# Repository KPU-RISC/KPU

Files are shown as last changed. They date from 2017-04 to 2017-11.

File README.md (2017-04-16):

# KPU - the RISC based Open Source CPU
This repository contains complete source code and buillding files for the KPU - a RISC based CPU (Central Processing Unit). The whole CPU is emulated, simulated, and modelled on the lowest level only with primitive AND, OR, XOR, and NOT gates.

It implements a 8-bit wide Data Bus, and a 16-bit wide Address Bus. The following 8-bit wide registers are implemented:
<ul>
<li><b>D</b> (General Purpose)</li>
<li><b>E</b> (General Purpose)</li>
<li><b>F</b> (General Purpose)</li>
<li><b>G</b> (General Purpose)</li>
<li><b>H</b> (General Purpose)</li>
<li><b>XL</b> (Lower part of the 16-bit wide "X" register</li>
<li><b>XH</b> (Upper part of the 16-bit wide "X" register</li>
</ul>

The following 16-bit wide registers are implemented:
<ul>
<li><b>SP</b> (Stack Pointer)</li>
<li><b>BP</b> (Base Pointer)</li>
<li><b>PC</b> (Program Counter)</li>
<li><b>M</b> (Memory Addressing)</li>
<li><b>J</b> (Jump Destination Addressing)</li>
<li><b>X</b> (General Purpose)</li>
<li><b>Y</b> (General Purpose)</li>
<li><b>Z</b> (General Purpose)</li>
</ul>

The project contains the following sub components:
<ul>
<li><b>Assembler</b>: The Assembler generates from the assembly language binary code that can be executed by the CPU. It is written in C#, and uses ANTLR for the syntax processing.</li>
<li><b>Emulation</b>: The C#-based Emulator is able to run binary code in a Console application or within a WinForms application (used for debugging purposes).</li>
<li><b>VHDL</b>: This folder contains the whole CPU implementation as VHDL description files.</li>
<li><b>Eagle</b>: This folder contains the whole schematics and board files ready for a physical implementation of the CPU based on 74LS TTL logic chips.</li>
<li><b>Logicly</b>: This folder contains early Proof-Of-Concept files for the Logicly simulation program.</li>
</ul>

For more detailed technical information about the CPU, please visit the project website at http://www.cpu-design.at

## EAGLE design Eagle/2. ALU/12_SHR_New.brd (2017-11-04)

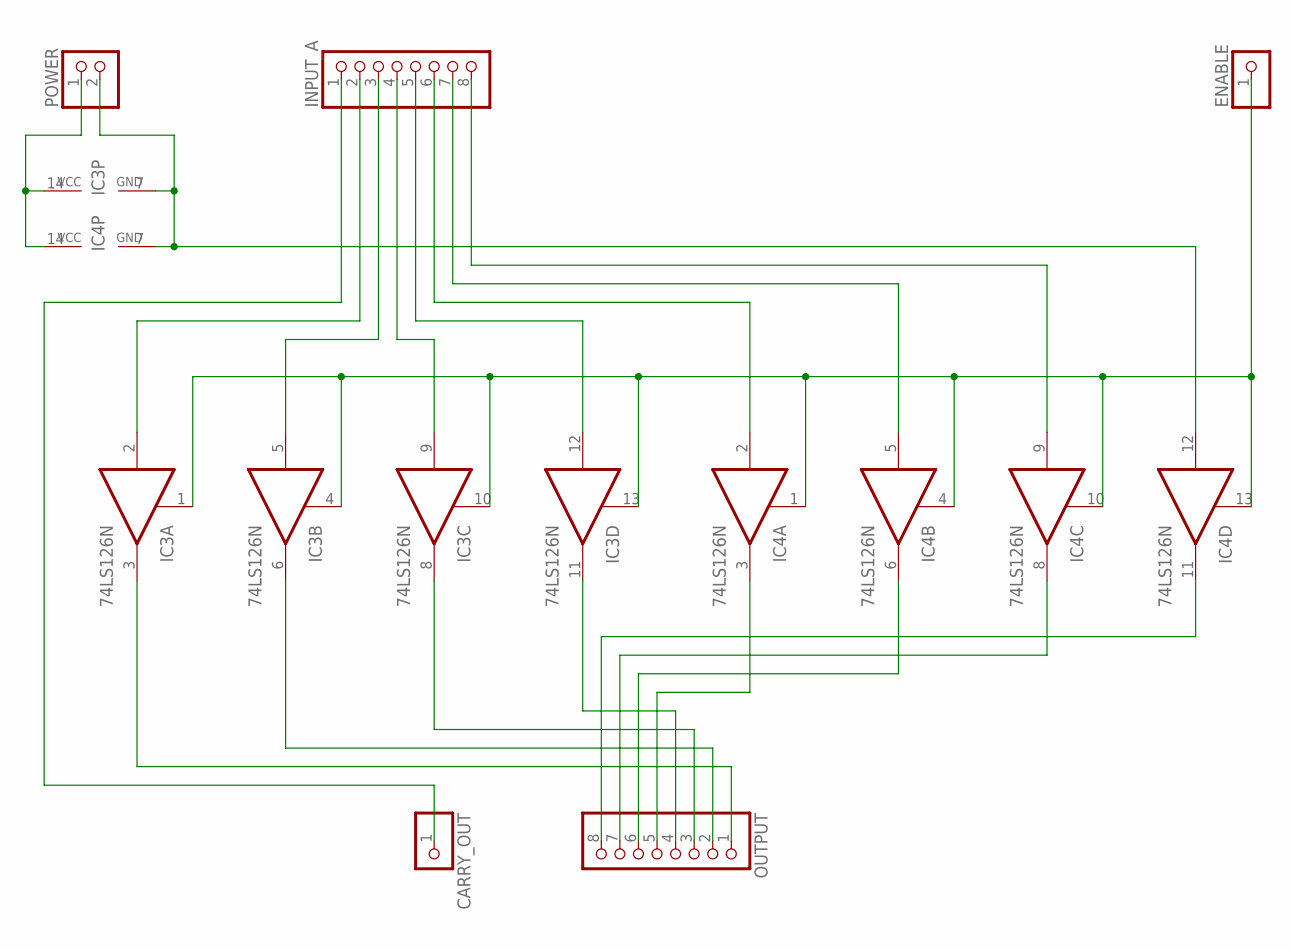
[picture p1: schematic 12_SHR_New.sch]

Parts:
CARRY_OUT: PINHD-1X1; 1X01
ENABLE: PINHD-1X1; 1X01
IC3, IC4: 74LS126N; DIL14
INPUT_A: PINHD-1X8; 1X08
OUTPUT: PINHD-1X8; 1X08
POWER: PINHD-1X2; 1X02

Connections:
GND: IC3.7 (GND), IC4.7 (GND), IC4.12 (I), POWER.2
unnamed: CARRY_OUT.1, INPUT_A.1
unnamed: IC3.2 (I), INPUT_A.2
unnamed: IC3.12 (I), INPUT_A.5
unnamed: IC4.2 (I), INPUT_A.6
unnamed: IC4.5 (I), INPUT_A.7
unnamed: IC4.9 (I), INPUT_A.8
unnamed: IC3.5 (I), INPUT_A.3
unnamed: IC3.9 (I), INPUT_A.4
unnamed: IC3.3 (O), OUTPUT.1
unnamed: IC3.6 (O), OUTPUT.2
unnamed: IC3.8 (O), OUTPUT.3
unnamed: IC3.11 (O), OUTPUT.4
unnamed: IC4.3 (O), OUTPUT.5
unnamed: IC4.6 (O), OUTPUT.6
unnamed: IC4.8 (O), OUTPUT.7
unnamed: IC4.11 (O), OUTPUT.8
unnamed: ENABLE.1, IC3.1 (OE), IC3.4 (OE), IC3.10 (OE), IC3.13 (OE), IC4.1 (OE), IC4.4 (OE), IC4.10 (OE), IC4.13 (OE)
VCC: IC3.14 (VCC), IC4.14 (VCC), POWER.1

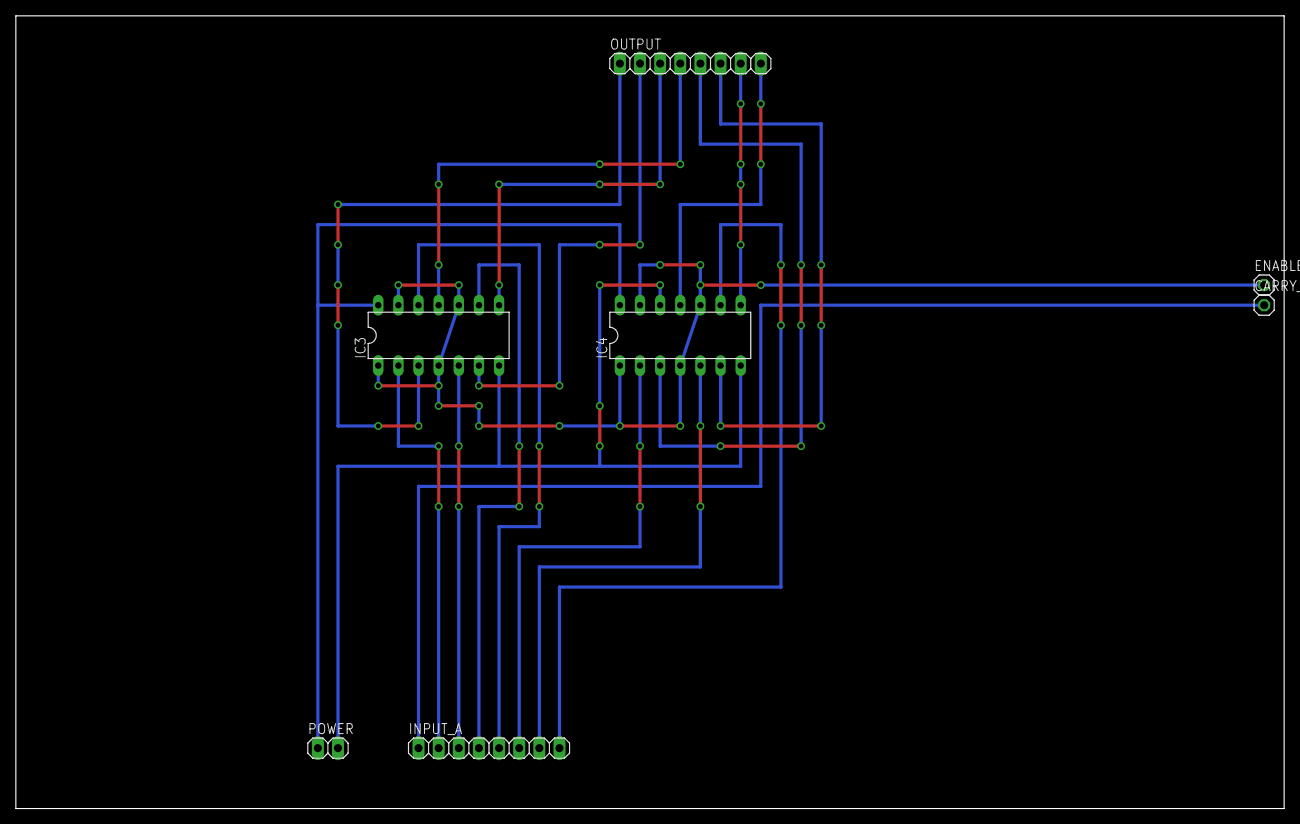
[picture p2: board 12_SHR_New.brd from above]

Board: 2 copper layers, 160.0 x 100.0 mm, 7 parts (0 on the bottom side), 19 nets.

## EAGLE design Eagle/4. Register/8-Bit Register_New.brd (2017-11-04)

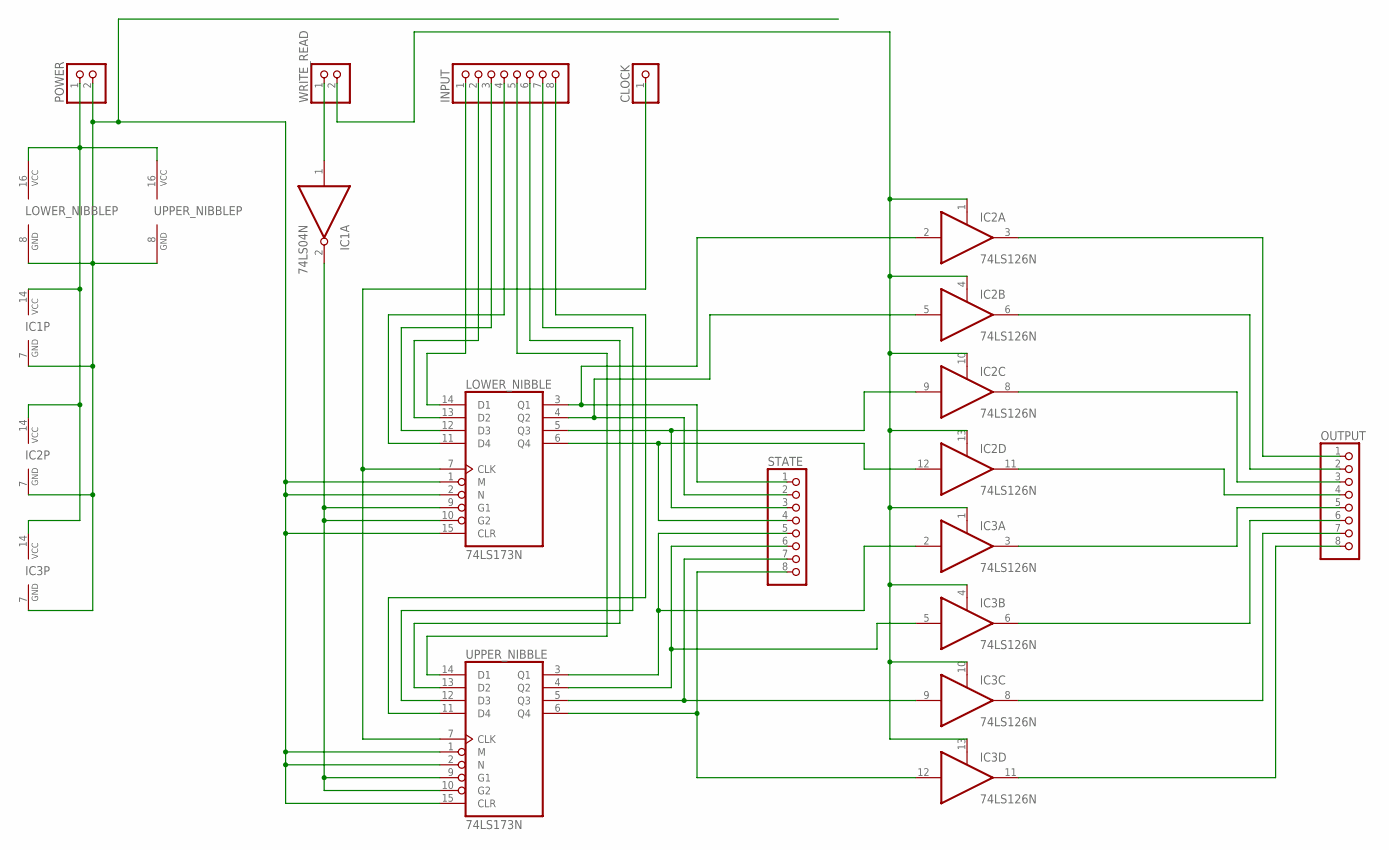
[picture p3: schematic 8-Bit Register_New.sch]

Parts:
CLOCK: PINHD-1X1; 1X01
IC1: 74LS04N; DIL14
IC2, IC3: 74LS126N; DIL14
INPUT: PINHD-1X8; 1X08
LOWER_NIBBLE: 74LS173N; DIL16
OUTPUT: PINHD-1X8; 1X08
POWER: PINHD-1X2; 1X02
STATE: PINHD-1X8; 1X08
UPPER_NIBBLE: 74LS173N; DIL16
WRITE_READ: PINHD-1X2; 1X02

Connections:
GND: IC1.7 (GND), IC2.7 (GND), IC3.7 (GND), LOWER_NIBBLE.1 (M), LOWER_NIBBLE.2 (N), LOWER_NIBBLE.8 (GND), LOWER_NIBBLE.15 (CLR), POWER.2, UPPER_NIBBLE.1 (M), UPPER_NIBBLE.2 (N), UPPER_NIBBLE.8 (GND), UPPER_NIBBLE.15 (CLR)
unnamed: IC2.12 (I), LOWER_NIBBLE.6 (Q4), STATE.4
unnamed: IC1.1 (I), WRITE_READ.1
unnamed: IC3.9 (I), STATE.7, UPPER_NIBBLE.5 (Q3)
unnamed: IC2.11 (O), OUTPUT.4
unnamed: IC1.2 (O), LOWER_NIBBLE.9 (G1), LOWER_NIBBLE.10 (G2), UPPER_NIBBLE.9 (G1), UPPER_NIBBLE.10 (G2)
unnamed: CLOCK.1, LOWER_NIBBLE.7 (CLK), UPPER_NIBBLE.7 (CLK)
unnamed: INPUT.1, LOWER_NIBBLE.14 (D1)
unnamed: INPUT.2, LOWER_NIBBLE.13 (D2)
unnamed: INPUT.3, LOWER_NIBBLE.12 (D3)
unnamed: INPUT.4, LOWER_NIBBLE.11 (D4)
unnamed: INPUT.6, UPPER_NIBBLE.13 (D2)
unnamed: INPUT.5, UPPER_NIBBLE.14 (D1)
unnamed: INPUT.7, UPPER_NIBBLE.12 (D3)
unnamed: INPUT.8, UPPER_NIBBLE.11 (D4)
unnamed: IC2.2 (I), LOWER_NIBBLE.3 (Q1), STATE.1
unnamed: IC2.5 (I), LOWER_NIBBLE.4 (Q2), STATE.2
unnamed: IC2.9 (I), LOWER_NIBBLE.5 (Q3), STATE.3
unnamed: IC3.2 (I), STATE.5, UPPER_NIBBLE.3 (Q1)
unnamed: IC3.5 (I), STATE.6, UPPER_NIBBLE.4 (Q2)
unnamed: IC3.12 (I), STATE.8, UPPER_NIBBLE.6 (Q4)
unnamed: IC2.1 (OE), IC2.4 (OE), IC2.10 (OE), IC2.13 (OE), IC3.1 (OE), IC3.4 (OE), IC3.10 (OE), IC3.13 (OE), WRITE_READ.2
unnamed: IC2.3 (O), OUTPUT.1
unnamed: IC2.6 (O), OUTPUT.2
unnamed: IC2.8 (O), OUTPUT.3
unnamed: IC3.3 (O), OUTPUT.5
unnamed: IC3.6 (O), OUTPUT.6
unnamed: IC3.8 (O), OUTPUT.7
unnamed: IC3.11 (O), OUTPUT.8
VCC: IC1.14 (VCC), IC2.14 (VCC), IC3.14 (VCC), LOWER_NIBBLE.16 (VCC), POWER.1, UPPER_NIBBLE.16 (VCC)

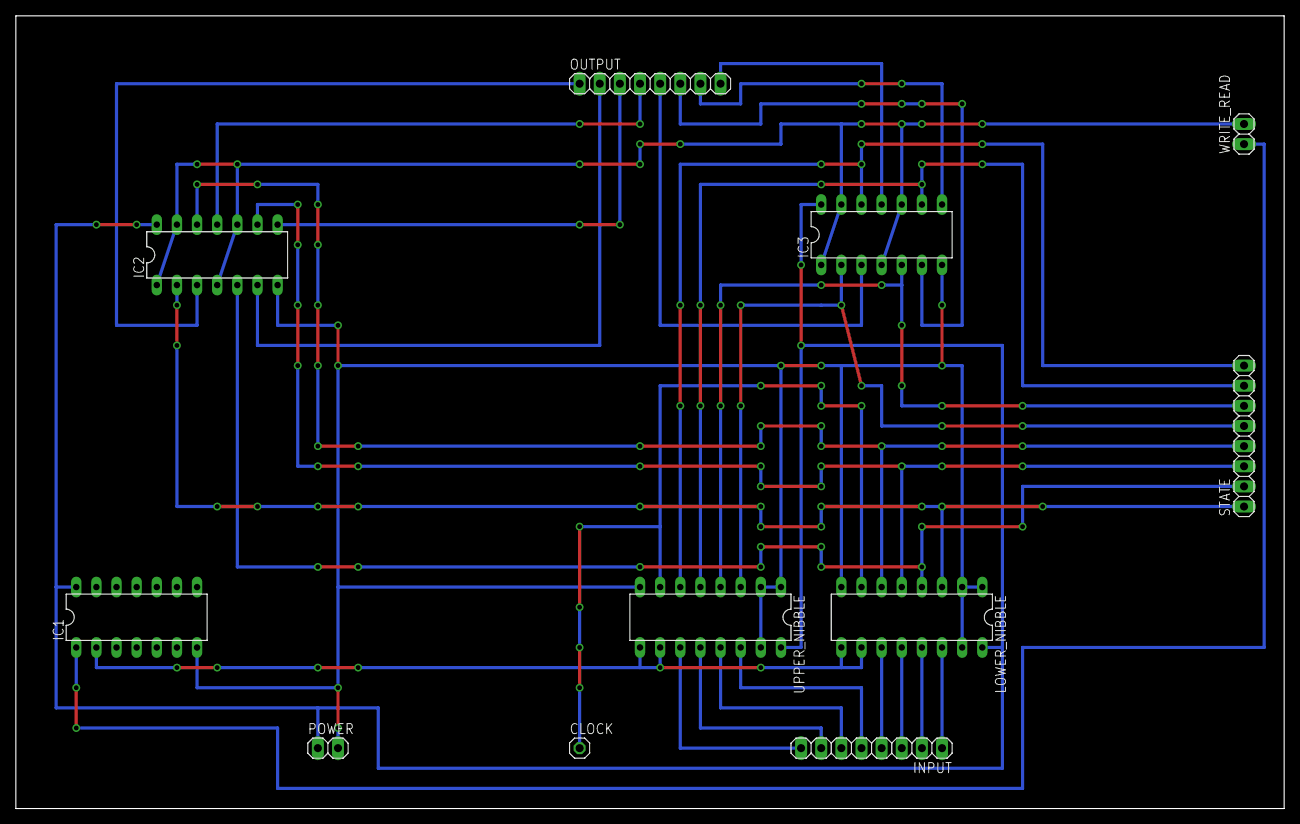
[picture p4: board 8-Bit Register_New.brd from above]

Board: 2 copper layers, 160.0 x 100.0 mm, 11 parts (0 on the bottom side), 30 nets.

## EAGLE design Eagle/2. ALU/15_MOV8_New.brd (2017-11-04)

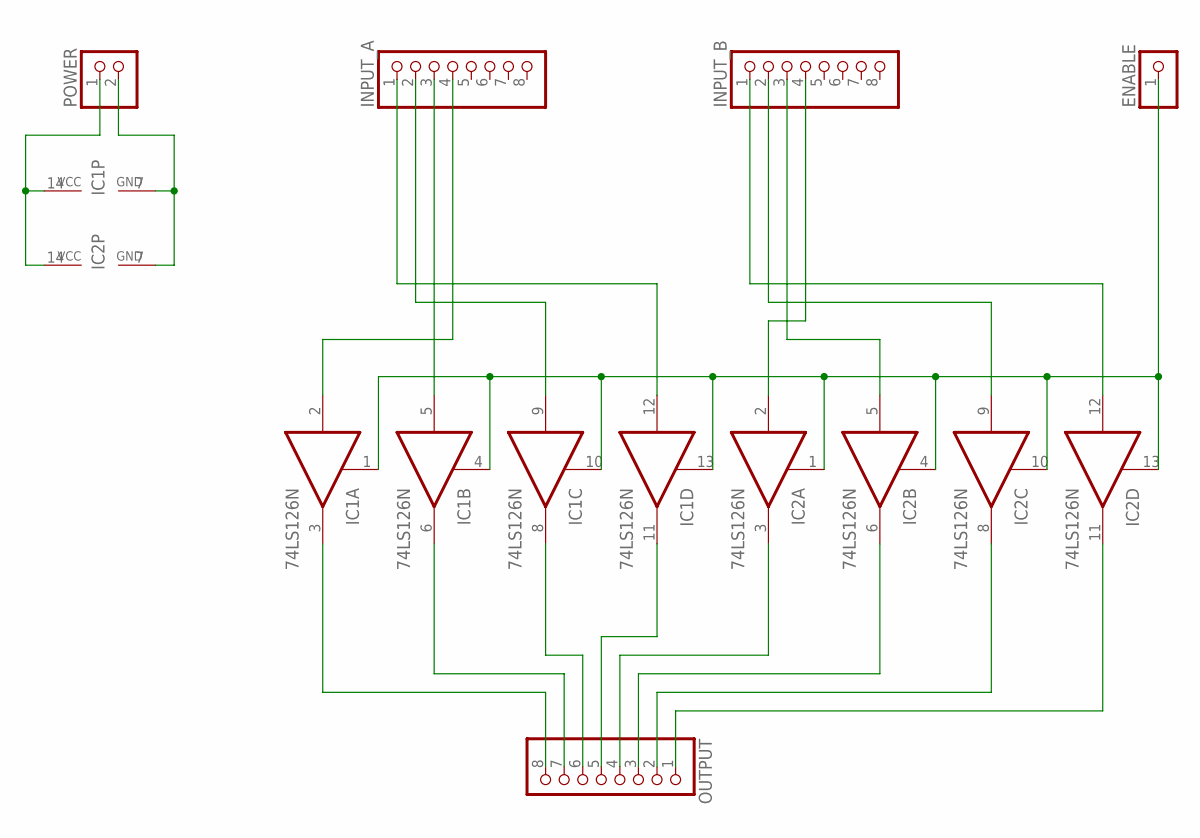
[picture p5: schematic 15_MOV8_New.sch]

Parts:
ENABLE: PINHD-1X1; 1X01
IC1, IC2: 74LS126N; DIL14
INPUT_A: PINHD-1X8; 1X08
INPUT_B: PINHD-1X8; 1X08
OUTPUT: PINHD-1X8; 1X08
POWER: PINHD-1X2; 1X02

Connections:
GND: IC1.7 (GND), IC2.7 (GND), POWER.2
unnamed: IC1.3 (O), OUTPUT.8
unnamed: IC1.6 (O), OUTPUT.7
unnamed: IC1.8 (O), OUTPUT.6
unnamed: IC1.11 (O), OUTPUT.5
unnamed: IC2.3 (O), OUTPUT.4
unnamed: IC2.6 (O), OUTPUT.3
unnamed: IC2.8 (O), OUTPUT.2
unnamed: IC2.11 (O), OUTPUT.1
unnamed: IC1.12 (I), INPUT_A.1
unnamed: IC1.9 (I), INPUT_A.2
unnamed: IC1.5 (I), INPUT_A.3
unnamed: IC1.2 (I), INPUT_A.4
unnamed: IC2.12 (I), INPUT_B.1
unnamed: IC2.9 (I), INPUT_B.2
unnamed: IC2.5 (I), INPUT_B.3
unnamed: IC2.2 (I), INPUT_B.4
unnamed: ENABLE.1, IC1.1 (OE), IC1.4 (OE), IC1.10 (OE), IC1.13 (OE), IC2.1 (OE), IC2.4 (OE), IC2.10 (OE), IC2.13 (OE)
VCC: IC1.14 (VCC), IC2.14 (VCC), POWER.1

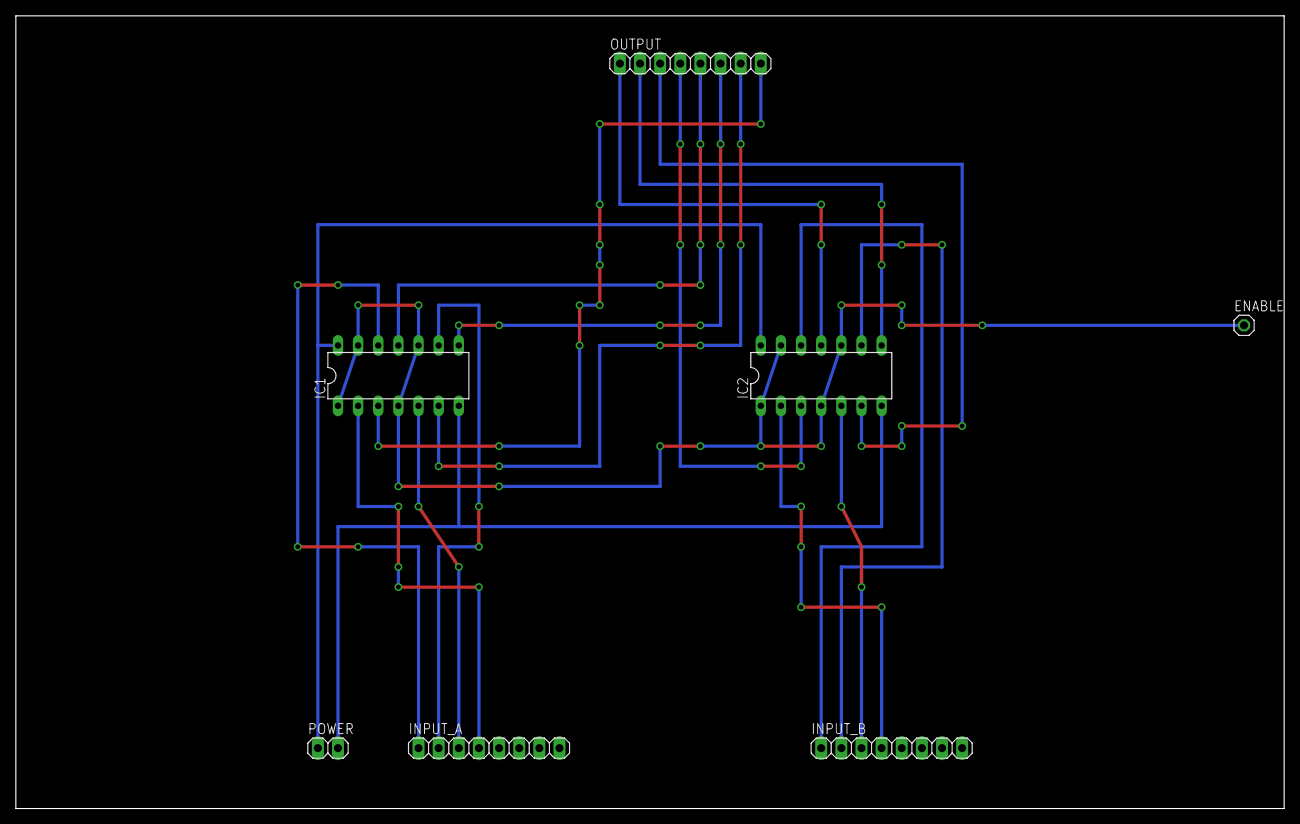
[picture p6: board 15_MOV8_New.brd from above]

Board: 2 copper layers, 160.0 x 100.0 mm, 7 parts (0 on the bottom side), 19 nets.

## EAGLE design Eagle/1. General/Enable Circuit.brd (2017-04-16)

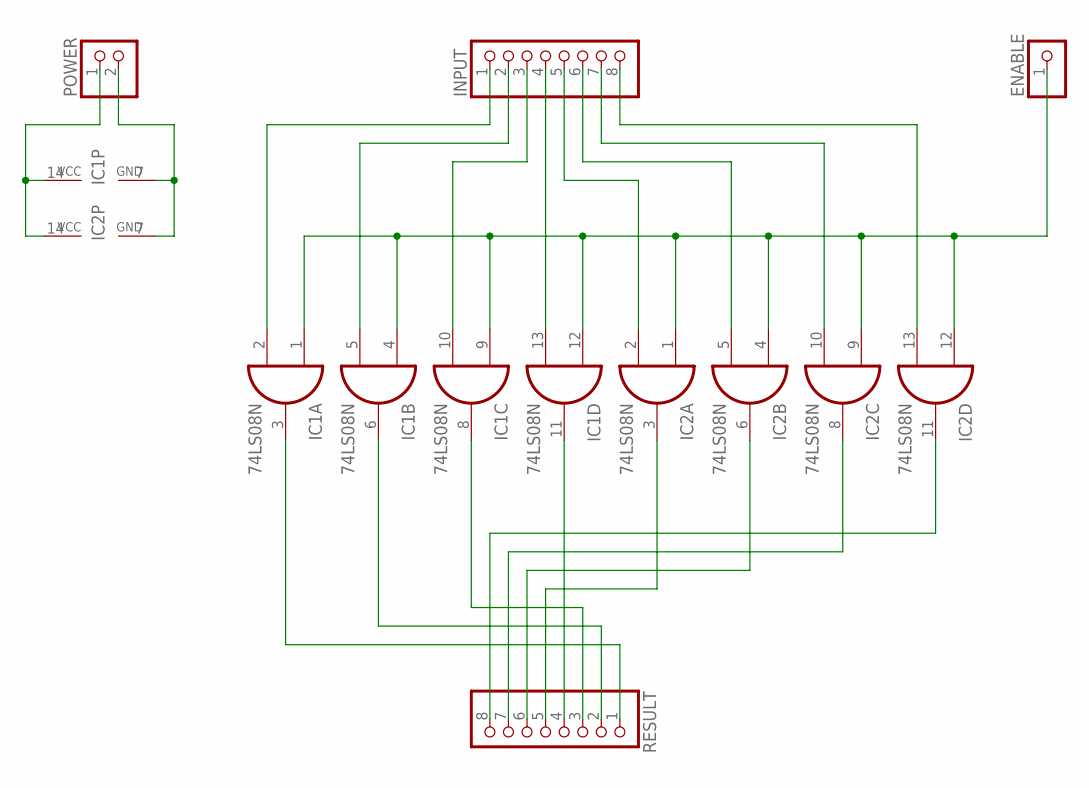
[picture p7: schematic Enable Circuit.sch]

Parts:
ENABLE: PINHD-1X1; 1X01
IC1, IC2: 74LS08N; DIL14
INPUT: PINHD-1X8; 1X08
POWER: PINHD-1X2; 1X02
RESULT: PINHD-1X8; 1X08

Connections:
GND: IC1.7 (GND), IC2.7 (GND), POWER.2
unnamed: IC1.2 (I1), INPUT.1
unnamed: IC1.5 (I1), INPUT.2
unnamed: IC1.10 (I1), INPUT.3
unnamed: IC1.13 (I1), INPUT.4
unnamed: IC2.2 (I1), INPUT.5
unnamed: IC2.5 (I1), INPUT.6
unnamed: IC2.10 (I1), INPUT.7
unnamed: IC2.13 (I1), INPUT.8
unnamed: ENABLE.1, IC1.1 (I0), IC1.4 (I0), IC1.9 (I0), IC1.12 (I0), IC2.1 (I0), IC2.4 (I0), IC2.9 (I0), IC2.12 (I0)
unnamed: IC1.3 (O), RESULT.1
unnamed: IC1.6 (O), RESULT.2
unnamed: IC1.8 (O), RESULT.3
unnamed: IC1.11 (O), RESULT.4
unnamed: IC2.3 (O), RESULT.5
unnamed: IC2.6 (O), RESULT.6
unnamed: IC2.8 (O), RESULT.7
unnamed: IC2.11 (O), RESULT.8
VCC: IC1.14 (VCC), IC2.14 (VCC), POWER.1

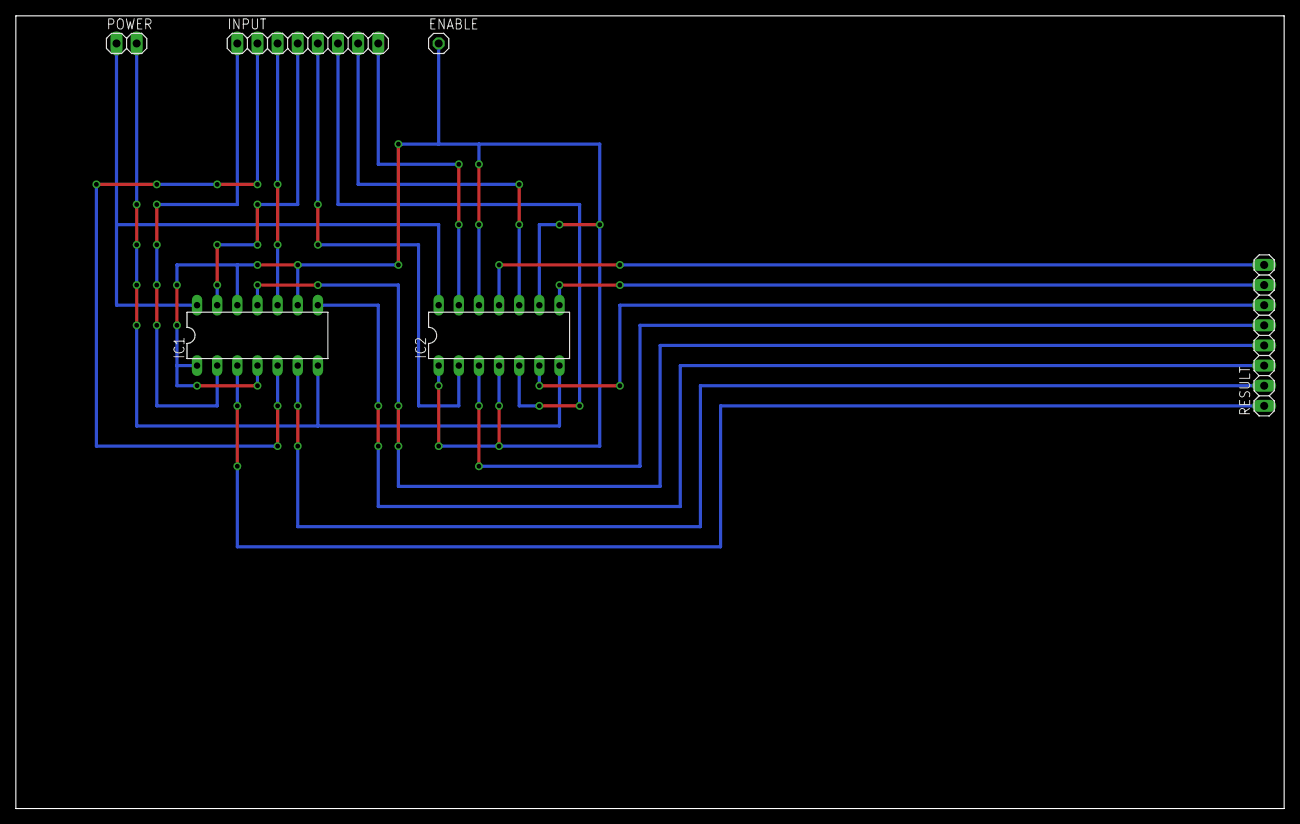
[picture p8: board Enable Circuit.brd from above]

Board: 2 copper layers, 160.0 x 100.0 mm, 6 parts (0 on the bottom side), 19 nets.

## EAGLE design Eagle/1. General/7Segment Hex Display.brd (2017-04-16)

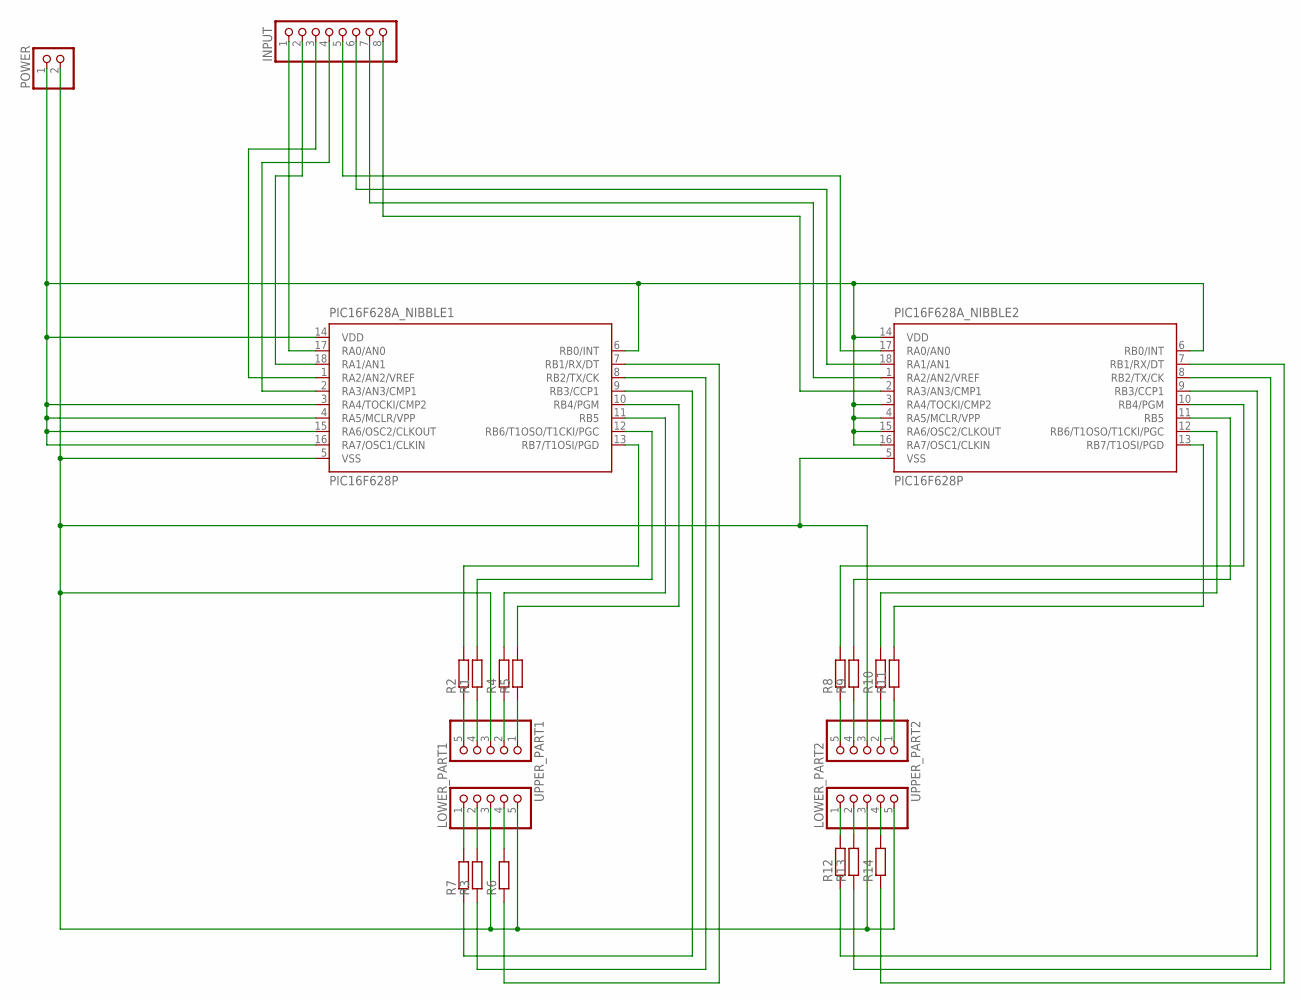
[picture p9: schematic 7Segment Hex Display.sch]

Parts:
INPUT: PINHD-1X8; 1X08
LOWER_PART1, LOWER_PART2: PINHD-1X5; 1X05
PIC16F628A_NIBBLE1, PIC16F628A_NIBBLE2: PIC16F628P; DIL18
POWER: PINHD-1X2; 1X02
R1, R2, R3, R4, R5, R6, R7, R8, R9, R10, R11, R12, R13, R14: R-EU_0207/10; 0207/10
UPPER_PART1, UPPER_PART2: PINHD-1X5; 1X05

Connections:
unnamed: INPUT.3, PIC16F628A_NIBBLE1.1 (RA2/AN2/VREF)
unnamed: INPUT.4, PIC16F628A_NIBBLE1.2 (RA3/AN3/CMP1)
unnamed: R2.1, UPPER_PART1.5
unnamed: PIC16F628A_NIBBLE1.13 (RB7/T1OSI/PGD), R2.2
unnamed: INPUT.2, PIC16F628A_NIBBLE1.18 (RA1/AN1)
unnamed: INPUT.1, PIC16F628A_NIBBLE1.17 (RA0/AN0)
unnamed: PIC16F628A_NIBBLE1.3 (RA4/TOCKI/CMP2), PIC16F628A_NIBBLE1.4 (RA5/MCLR/VPP), PIC16F628A_NIBBLE1.6 (RB0/INT), PIC16F628A_NIBBLE1.14 (VDD), PIC16F628A_NIBBLE1.15 (RA6/OSC2/CLKOUT), PIC16F628A_NIBBLE1.16 (RA7/OSC1/CLKIN), PIC16F628A_NIBBLE2.3 (RA4/TOCKI/CMP2), PIC16F628A_NIBBLE2.4 (RA5/MCLR/VPP), PIC16F628A_NIBBLE2.6 (RB0/INT), PIC16F628A_NIBBLE2.14 (VDD), PIC16F628A_NIBBLE2.15 (RA6/OSC2/CLKOUT), PIC16F628A_NIBBLE2.16 (RA7/OSC1/CLKIN), POWER.1
unnamed: LOWER_PART1.3, LOWER_PART1.5, LOWER_PART2.3, LOWER_PART2.5, PIC16F628A_NIBBLE1.5 (VSS), PIC16F628A_NIBBLE2.5 (VSS), POWER.2, UPPER_PART1.3, UPPER_PART2.3
unnamed: PIC16F628A_NIBBLE1.12 (RB6/T1OSO/T1CKI/PGC), R1.2
unnamed: R1.1, UPPER_PART1.4
unnamed: PIC16F628A_NIBBLE1.8 (RB2/TX/CK), R3.1
unnamed: PIC16F628A_NIBBLE1.11 (RB5), R4.2
unnamed: PIC16F628A_NIBBLE1.10 (RB4/PGM), R5.2
unnamed: LOWER_PART1.2, R3.2
unnamed: R4.1, UPPER_PART1.2
unnamed: R5.1, UPPER_PART1.1
unnamed: PIC16F628A_NIBBLE1.9 (RB3/CCP1), R7.1
unnamed: LOWER_PART1.1, R7.2
unnamed: PIC16F628A_NIBBLE2.7 (RB1/RX/DT), R14.1
unnamed: PIC16F628A_NIBBLE1.7 (RB1/RX/DT), R6.1
unnamed: LOWER_PART1.4, R6.2
unnamed: R8.1, UPPER_PART2.5
unnamed: INPUT.5, PIC16F628A_NIBBLE2.17 (RA0/AN0)
unnamed: INPUT.6, PIC16F628A_NIBBLE2.18 (RA1/AN1)
unnamed: INPUT.7, PIC16F628A_NIBBLE2.1 (RA2/AN2/VREF)
unnamed: INPUT.8, PIC16F628A_NIBBLE2.2 (RA3/AN3/CMP1)
unnamed: R9.1, UPPER_PART2.4
unnamed: R10.1, UPPER_PART2.2
unnamed: R11.1, UPPER_PART2.1
unnamed: LOWER_PART2.1, R12.2
unnamed: LOWER_PART2.2, R13.2
unnamed: LOWER_PART2.4, R14.2
unnamed: PIC16F628A_NIBBLE2.13 (RB7/T1OSI/PGD), R11.2
unnamed: PIC16F628A_NIBBLE2.12 (RB6/T1OSO/T1CKI/PGC), R10.2
unnamed: PIC16F628A_NIBBLE2.11 (RB5), R9.2
unnamed: PIC16F628A_NIBBLE2.10 (RB4/PGM), R8.2
unnamed: PIC16F628A_NIBBLE2.9 (RB3/CCP1), R12.1
unnamed: PIC16F628A_NIBBLE2.8 (RB2/TX/CK), R13.1

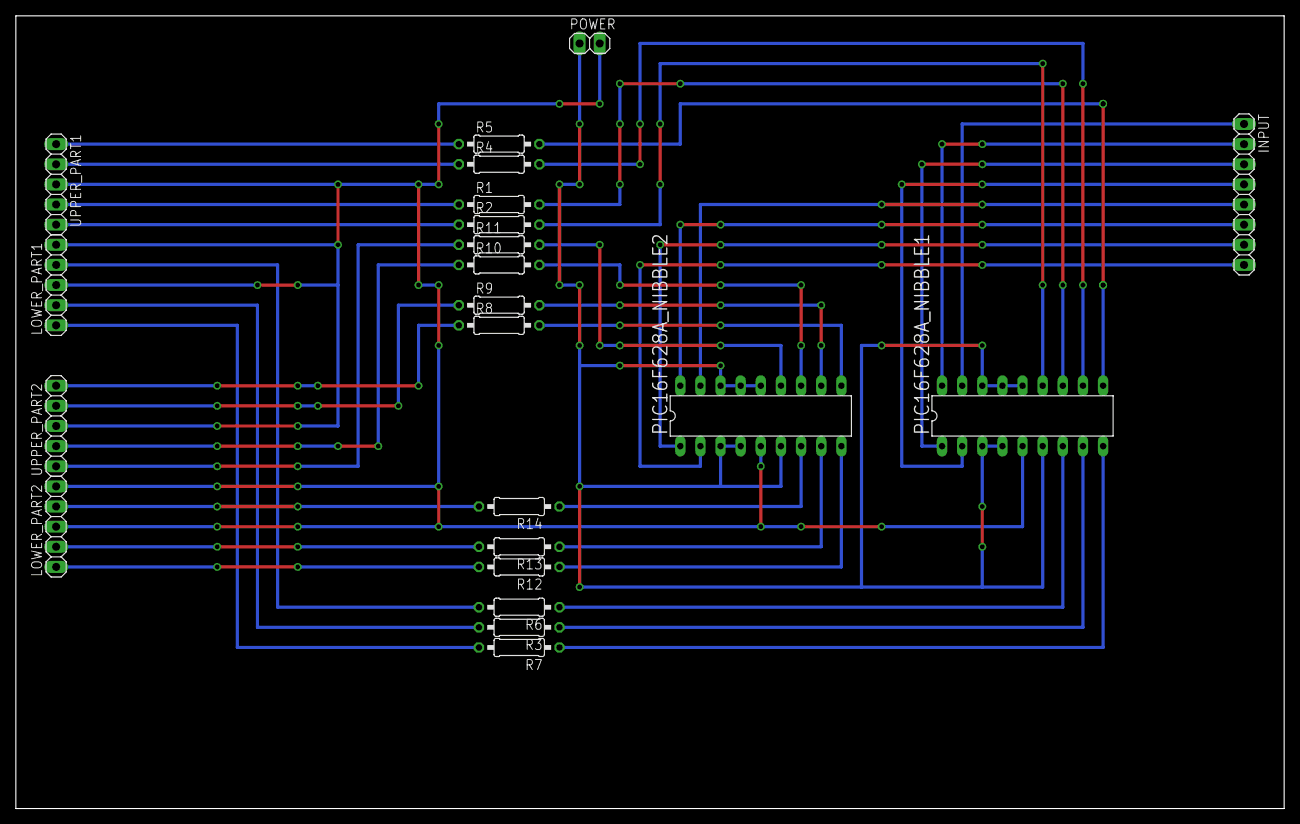
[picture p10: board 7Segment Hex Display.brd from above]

Board: 2 copper layers, 160.0 x 100.0 mm, 22 parts (0 on the bottom side), 38 nets.

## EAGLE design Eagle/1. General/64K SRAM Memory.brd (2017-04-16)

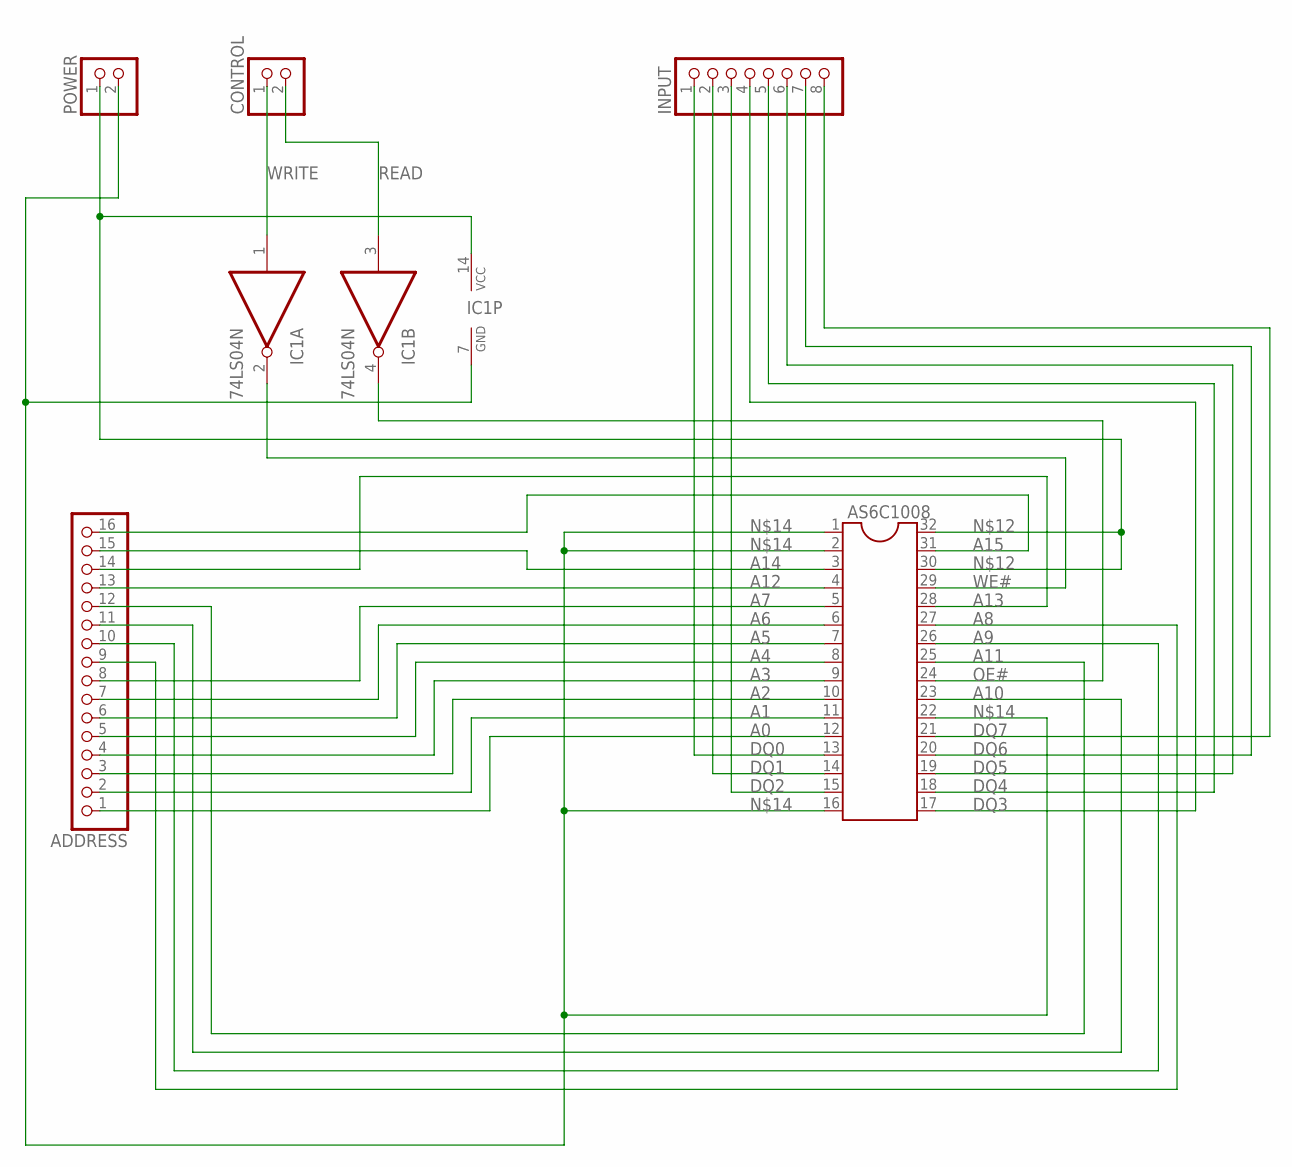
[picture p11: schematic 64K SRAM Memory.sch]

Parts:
ADDRESS: PINHD-1X16; 1X16
AS6C1008: DIL32
CONTROL: PINHD-1X2; 1X02
IC1: 74LS04N; DIL14
INPUT: PINHD-1X8; 1X08
POWER: PINHD-1X2; 1X02

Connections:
A0: ADDRESS.1, AS6C1008.12
A1: ADDRESS.2, AS6C1008.11
A2: ADDRESS.3, AS6C1008.10
A3: ADDRESS.4, AS6C1008.9
A4: ADDRESS.5, AS6C1008.8
A5: ADDRESS.6, AS6C1008.7
A6: ADDRESS.7, AS6C1008.6
A7: ADDRESS.8, AS6C1008.5
A8: ADDRESS.9, AS6C1008.27
A9: ADDRESS.10, AS6C1008.26
A10: ADDRESS.11, AS6C1008.23
A11: ADDRESS.12, AS6C1008.25
A12: ADDRESS.13, AS6C1008.4
A13: ADDRESS.14, AS6C1008.28
A14: ADDRESS.15, AS6C1008.3
A15: ADDRESS.16, AS6C1008.31
DQ0: AS6C1008.13, INPUT.1
DQ1: AS6C1008.14, INPUT.2
DQ2: AS6C1008.15, INPUT.3
DQ3: AS6C1008.17, INPUT.4
DQ4: AS6C1008.18, INPUT.5
DQ5: AS6C1008.19, INPUT.6
DQ6: AS6C1008.20, INPUT.7
DQ7: AS6C1008.21, INPUT.8
unnamed: AS6C1008.30, AS6C1008.32, IC1.14 (VCC), POWER.1
unnamed: AS6C1008.1, AS6C1008.2, AS6C1008.16, AS6C1008.22, IC1.7 (GND), POWER.2
OE#: AS6C1008.24, IC1.4 (O)
READ: CONTROL.2, IC1.3 (I)
WE#: AS6C1008.29, IC1.2 (O)
WRITE: CONTROL.1, IC1.1 (I)

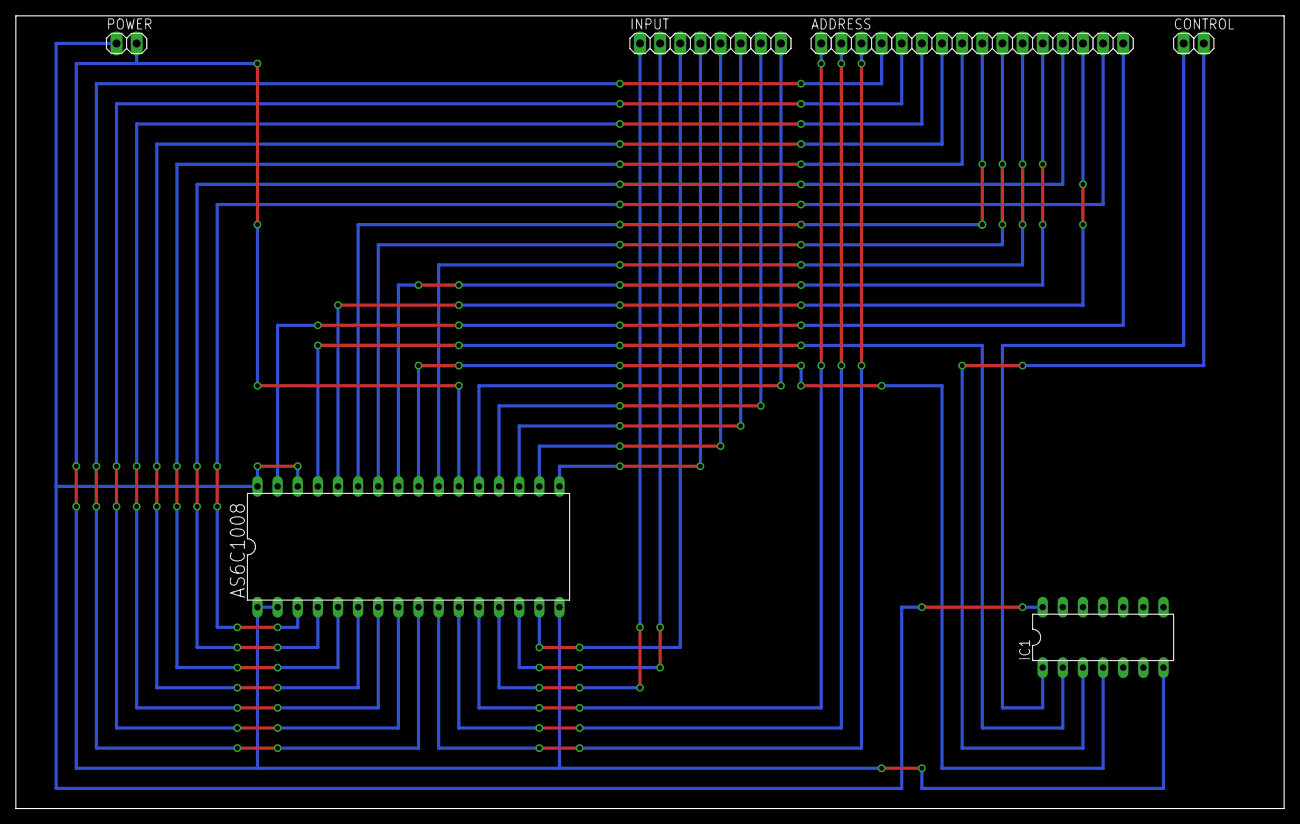
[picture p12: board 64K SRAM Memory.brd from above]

Board: 2 copper layers, 160.0 x 100.0 mm, 6 parts (0 on the bottom side), 30 nets.

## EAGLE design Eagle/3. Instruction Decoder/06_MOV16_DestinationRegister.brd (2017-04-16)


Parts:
IC2, IC3, IC4, IC5: 74LS08N; DIL14
INSTRUCTION: PINHD-1X1; 1X01
POWER: PINHD-1X2; 1X02
RESULT: PINHD-1X8; 1X08
SOURCE_REGISTER: PINHD-1X8; 1X08
T_STATE: PINHD-1X8; 1X08

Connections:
GND: IC2.7 (GND), IC3.7 (GND), IC4.7 (GND), IC5.7 (GND), POWER.2
unnamed: IC2.4 (I0), IC2.12 (I0), IC3.4 (I0), IC3.12 (I0), IC4.9 (I0), IC4.12 (I0), IC5.9 (I0), IC5.12 (I0), T_STATE.5
unnamed: IC2.2 (I1), IC2.10 (I1), IC3.2 (I1), IC3.10 (I1), IC4.2 (I1), IC4.5 (I1), IC5.2 (I1), IC5.5 (I1), INSTRUCTION.1
unnamed: IC2.1 (I0), SOURCE_REGISTER.1
unnamed: IC2.3 (O), IC2.5 (I1)
unnamed: IC2.6 (O), RESULT.8
unnamed: IC2.9 (I0), SOURCE_REGISTER.2
unnamed: IC2.8 (O), IC2.13 (I1)
unnamed: IC3.1 (I0), SOURCE_REGISTER.3
unnamed: IC2.11 (O), RESULT.7
unnamed: IC3.3 (O), IC3.5 (I1)
unnamed: IC3.6 (O), RESULT.6
unnamed: IC3.9 (I0), SOURCE_REGISTER.4
unnamed: IC3.8 (O), IC3.13 (I1)
unnamed: IC3.11 (O), RESULT.5
unnamed: IC4.1 (I0), SOURCE_REGISTER.5
unnamed: IC4.3 (O), IC4.10 (I1)
unnamed: IC4.8 (O), RESULT.4
unnamed: IC4.4 (I0), SOURCE_REGISTER.6
unnamed: IC4.6 (O), IC4.13 (I1)
unnamed: IC4.11 (O), RESULT.3
unnamed: IC5.1 (I0), SOURCE_REGISTER.7
unnamed: IC5.3 (O), IC5.10 (I1)
unnamed: IC5.8 (O), RESULT.2
unnamed: IC5.4 (I0), SOURCE_REGISTER.8
unnamed: IC5.6 (O), IC5.13 (I1)
unnamed: IC5.11 (O), RESULT.1
VCC: IC2.14 (VCC), IC3.14 (VCC), IC4.14 (VCC), IC5.14 (VCC), POWER.1

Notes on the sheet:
T-State #4


Board: 2 copper layers, 160.0 x 100.0 mm, 9 parts (0 on the bottom side), 28 nets.

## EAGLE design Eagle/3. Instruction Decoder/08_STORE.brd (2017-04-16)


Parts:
IC1: 74LS04N; DIL14
IC2, IC4: 74LS08N; DIL14
IC3: 74LS32N; DIL14
INSTRUCTION: PINHD-1X8; 1X08
INSTRUCTION_RESULT: PINHD-1X1; 1X01
POWER: PINHD-1X2; 1X02
RESULT: PINHD-1X2; 1X02
T_STATE: PINHD-1X8; 1X08

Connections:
GND: IC1.7 (GND), IC2.7 (GND), IC3.7 (GND), IC4.7 (GND), POWER.2
unnamed: IC2.2 (I1), INSTRUCTION.4
unnamed: IC1.3 (I), INSTRUCTION.6
unnamed: IC1.5 (I), INSTRUCTION.7
unnamed: IC2.1 (I0), INSTRUCTION.5
unnamed: IC2.3 (O), IC2.5 (I1)
unnamed: IC1.4 (O), IC2.4 (I0)
unnamed: IC2.6 (O), IC2.10 (I1)
unnamed: IC1.6 (O), IC2.9 (I0)
unnamed: IC2.8 (O), IC2.13 (I1)
unnamed: IC2.12 (I0), INSTRUCTION.8
unnamed: IC3.2 (I1), T_STATE.5
unnamed: IC3.1 (I0), IC4.4 (I0), T_STATE.6
unnamed: IC2.11 (O), IC4.2 (I1), IC4.5 (I1), INSTRUCTION_RESULT.1
unnamed: IC3.3 (O), IC4.1 (I0)
unnamed: IC4.6 (O), RESULT.2
RESULT: IC4.3 (O), RESULT.1
VCC: IC1.14 (VCC), IC2.14 (VCC), IC3.14 (VCC), IC4.14 (VCC), POWER.1

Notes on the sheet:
STORE Instruction: 10011SSS
T4 or T5
#1: Select_M_To_AddressBus #2: Select_SRAM_Store


Board: 2 copper layers, 160.0 x 100.0 mm, 9 parts (0 on the bottom side), 18 nets.

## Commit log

2017-04-16 Added Assembly Code
2017-04-16 Added Eagle files
    [01_FETCH_INCREMENT.brd, 01_FETCH_INCREMENT.sch, 01_XOR.brd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]
2017-04-16 Assembly example for INT usage.
2017-10-26 New Layout for SHL ALU operation
    [06_SHL_New.brd, 06_SHL_New.sch]
2017-11-04 Added new schematics.
    [05_NOT_New.brd, 05_NOT_New.sch, 12_SHR_New.brd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]
